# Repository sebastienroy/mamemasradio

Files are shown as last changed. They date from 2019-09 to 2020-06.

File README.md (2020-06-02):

# Mamema's radio
A web radio receiver with a classical hifi style ergonomy

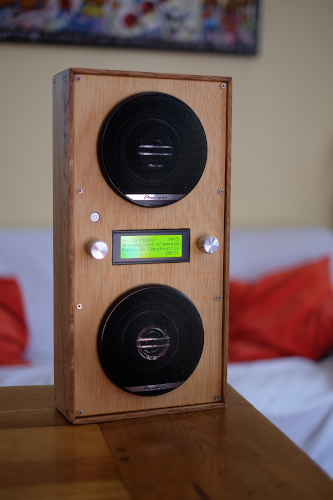
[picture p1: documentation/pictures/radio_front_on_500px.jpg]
Mamema's radio


## History

During the hollidays of my children, I've asked my mother, the grandmother of my children, to babysit them. During this period, my children were often listening to FIP radio (www.fip.fr) on the FM. My mother really liked listening to this radio. Unfortunately, when she was back to home, she couldn't listen to it any more because the FM station is not vailable where she lives (in the north of Alsace, France).
This gave me an idea of Christmas present : I decided to build a radio receiver. Instead of receiving the radio stream from FM, the receiver will get it from web. A quick tour on some web stores shown me that webradio receiver are available for purchasing, however the receiver I wanted for my mother had to meet the following two requirements :
* To be very easy to use, having an ergonomy very close to a traditional FM radio receiver
* Being highly customisable (and customized), in order to help her, each time she listens to the radio, to have a though for her children and grandchildren.

In Alsace, where she lives, the word for "Grandmother" is "Mamema". This is the word my children use for her, and so this is the name I used for this radio receiver.

## Features
* Plays audio stream through wifi network. No limit for the number of programmable radio stations
* Can also be used as a bluetooth speaker
* Uses classics physical commands : power button, rotary buttons
* Built around a raspberry pi zero low cost - low power consumption nano computer
* Excellent audio quality : uses a high quality sound card.
* Displays personnalisable messages and birthdays reminders : perfect as a present for your family members. No limitation for the length of the message, the text scrolls if wider than the screen
* Can be built as a standalone radio, integrating speakers and an amplifier, or as an audio source for a separated stereo amplifier

## General design
### Hardware
* Raspberry Pi Zero W
* Soundcard :  Hifiberry Miniamp (standalone radio), or Hifiberry DAC+ Zero (audio source for external hifi amplifier)
* Loud speakers (standalone radio)
* Man-Machine interface elements : LCD display, rotary encoder, power button
* Interface pcb and accessories pcb : a way to make electrical links from the Raspberry GPIO ports and the interface elements. To be manufactured by a dedicated factory (links provided)
* Casing.
### Software
* Radio stream player (Music Player Daemon)
* User interactions managed by python software components (specific developments)
* Based on Raspbian operating system

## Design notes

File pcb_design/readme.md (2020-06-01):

# Mamema's radio pcb design
This directory contains the design document describing the pcb design of the webradio.

The pcb consists in a main interface pcb and some accessories pcb

* Main pcb :

main pcb schema

* Accessories pcb :

accessories pcb schema

## Purpose of the pcb
The Mamema's radio hardware consists in the following components
* A Raspberry pi zero W nano computer
* A sound card (hifiberry miniamp, or DAC+ zero)
* A power button
* A 4x20 LCD display
* 1 or 2 rotary encoders

All these elements are driven from the Raspberry pi GPIO connector. However, because the soundcard is blugged as a hat onto the GPIO port, if the sound courd is plugged directly on the GPIO port, the port would not be available for other physical components.
The idea is then to insert a PCB between the raspberry pi and the sound card, so that the sound card can have access to needed pins, and the remaining free pins are available for the other physical components.

## Manufacturing
Main PCB and accessories PCB may be manufactured directly using these links :
* Main PCB :
https://aisler.net/p/ENDPOVDQ
* Accessories PCB :
https://aisler.net/p/QHNAFNPG

The accessories board has to be cut into 6 parts : 4 rotary encoder supports, and 2 power button supports. Thus, one accessories board can be used to make two separate Mamema's radios.

The design has been made using Fritzing 0.9.3b.
Unfortunately, Fritzing org currently asks people for paying to download the software, witch was not the case when Mamema's radio design was made.
If you don't want to pay, you can still compile the sources by yourself.

## Design documents

* webradio_pcb.fzz document describes the main pcb of the web radio. It is used to connect the raspberry pi zero w component to an LCD display, a power button, a rotary encoder used to change the radio station, and optionnaly to another rotary encoder that can be used to change the volume. This pcb also holds a logic level converter (in order to convert voltage from 3.3V from the raspberry to 5V for the LCD display) and a resistor needed for the power button LED.
* accessories_pcb.fzz document describes accessories pcb. The described pcb has to be cut into 6 parts as described above. These parts are used as support to connect the rotary encoder and the power button, but they are also used to attach these components on the case of the radio. The power button in particular cannot be attached on the case by itself.

The connection between the main pcb and the accessories pcb use F2510-4P connectors. The male F2510-4P headers are soldered on the main pcbs, male dupont headers are soldered on the accessories pcb.
Wires are used between them.
The female headers are used from the main pcb to the accessories pcb.

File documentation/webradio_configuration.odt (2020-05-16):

# Installation Raspbian

Gravage de la carte SD à partir de la distrib raspbian strech lite

# Personnalisation de l’OS

Se connecter avec un clavier et un écran, brancher l’alim

L’utilisateur par défaut est : pi

le mot de passe par défaut est : raspberry

Taper sudo raspi-config

- configurer le clavier : le mettre en Francais
- Configurer le wifi
- Configurer le hostname (webradio par exemple)
- Configurer un nouveau mot de passe
- Autoriser l’interface i2c
- Autoriser SSH
- Valider
- Rebooter et noter l’adresse IP. Le reste pourra se faire par SSH

# Activation et configuration du module logiciel I²C

Voire référence en fin de document

On ajoute les modules au démarrage :

sudo nano /etc/modules

Ajouter ces 2 lignes :

i2c-bcm2708

i2c-dev

On redémarre :

sudo reboot

On installe les outils nécessaires :

sudo apt-get install python-smbus i2c-tools

On va utiliser la commande i2cdetect, qui permet de voir la liste des périphériques I²C reliés au Pi. La commande est différente si vous utilisez un Raspberry Pi Rev 1 ou Rev 2 (l’adresse du bus I²C est différente), donc choisissez la bonne :

sudo i2cdetect -y 1

0 1 2 3 4 5 6 7 8 9 a b c d e f

00: -- -- -- -- -- -- -- -- -- -- -- -- --

10: -- -- -- -- -- -- -- -- -- -- -- -- -- -- -- --

20: -- -- -- -- -- -- -- 27 -- -- -- -- -- -- -- --

30: -- -- -- -- -- -- -- -- -- -- -- -- -- -- -- --

40: -- -- -- -- -- -- -- -- -- -- -- -- -- -- -- --

50: -- -- -- -- -- -- -- -- -- -- -- -- -- -- -- --

60: -- -- -- -- -- -- -- -- -- -- -- -- -- -- -- --

70: -- -- -- -- -- -- -- --

Ici, on peut voir qu’il y a un composant i2c, à l’adresse 0x27.

Il faudra reporter cette valeur dans le fichier webradio.cfg :

Dans ce dernier fichier, vous pouvez ajuster l’adresse de votre écran si ce n’est pas 27 :

[hardware]

# i2c address of the lcd device

lcd_address: 0x27

## Utilisateur par défaut

On laisse pi, ya pas de pb avec ça

# Partage du répertoire de configuration (optionnel)

Il est aussi possible d’utiliser sftp (ssh) à la place.

L’info est détaillée là :

https://raspberrypihq.com/how-to-share-a-folder-with-a-windows-computer-from-a-raspberry-pi/

Installer smb :

sudo apt-get update

sudo apt-get install samba samba-common-bin

Créer un répertoire de partage :

mkdir /home/pi/share

Editer le fichier de conf de Samba :

sudo nano /etc/samba/smb.conf

Assurez vous que les paramètres suivants sont positionnés :

workgroup = WORKGROUP

wins support = yes

Rajoutez la section suivante :

[RadioShare]

comment=Webradio Share

path=/home/pi/share

browseable=Yes

writeable=Yes

only guest=no

create mask=0777

directory mask=0777

public=no

Enregistrer et quitter.

Créer un utilisateur smb :

sudo smbpasswd -a pi

# Installation du logiciel radio

## Copie des fichiers

Copie des fichiers à partir du répertoire partagé RadioShare

Copier les fichiers dans /home/pi/webradio

## configuration pour démarrage auto de la radio

Vérifier que les paths figurant dans /home/pi/webradio/webradio.sh sont ceux attendus

Copier le fichier weradio.sh dans /etc/rc.local/

sudo cp /home/pi/webradio/webradio.sh /etc/rc.local

# Configuration de la carte son

Dans le fichier /boot/config.txt

Enlever la ligne

dtparam=audio=on

Rajouter la ligne

dtoverlay=hifiberry-dac

# Installer MPD

Sudo apt-get update

Sudo apt-get install mpd mpc

Puis rebooter : sudo reboot

# Configuration du volume

Créer un fichier /etc/asound.conf contenant :

pcm.hifiberry {

type softvol

slave.pcm "plughw:0"

control.name "Master"

control.card 0

}

pcm.!default {

type plug

slave.pcm "hifiberry"

}

Modifier le fichier /etc/mpd.conf : la section audio_output{…} doit contenir ceci :

audio_output {

enabled "yes"

type "alsa"

name "HiFiBerry Miniamp"

device "hifiberry"

auto_resample "no"

auto_channels "no"

auto_format "no"

dop "no"

mixer_control "Master" # optional

mixer_type "hardware" # optional

}

sudo reboot

# tester le son et le flux radio

mpc add http://str0.creacast.com/rec

mpc play 1

# Configurer le bluetooth

Le seul parametre à modifier au déploiement est nécessaire à la configuration du raspberry en tant que « a2dp receiver ». (advanced audio distribution profile)

Ouvrez le fichier de configuration de bluealsa :

sudo nano /lib/systemd/system/bluealsa.service

Cherchez la ligne qui commence par « ExecStart » et rajoutez l’option du profile a2dp comme ci-dessous :

ExecStart=/usr/bin/bluealsa -p a2dp-sink

# Configurer un agent bluetooth

https://gist.github.com/mill1000/74c7473ee3b4a5b13f6325e9994ff84c

# Webradio

Copier les sources python dans le répertoire webradio

Installer les dépendances python :

Rpi.GPIO :

sudo apt-get install python-rpi.gpio python3-rpi.gpio

RPLCD :

sudo apt install python3-smbus

sudo apt-get install python3-pip

sudo pip3 install RPLCD

# Startup at boot

Rajouter dans le fichier /etc/rc.local

python3 /home/pi/python/webradio/mamemasradio.py > /dev/null &

# Ecrire les logs systeme en RAM

Editer le fichier /etc/fstab

Rajouter les lignes suivantes :

tmpfs /tmp tmpfs defaults,noatime,nosuid,size=10m 0 0

tmpfs /var/tmp tmpfs defaults,noatime,nosuid,size=10m 0 0

tmpfs /var/log tmpfs defaults,noatime,nosuid,mode=0755,size=10m 0 0

tmpfs /var/log/mpd tmpfs defaults,noatime,nosuid,mode=0755,size=10m 0 0

# Modifier le mot de passe

Nouveau mot de passe :

Nicole-48

Taper la commande

passwd

Le mot de passe initial est

raspberry

# Références

http://hardware-libre.fr/2014/03/raspberry-pi-utiliser-un-lcd-4x20/

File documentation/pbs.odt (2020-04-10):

Hardware

Ref | Nom | Commentaire | Nb
1 | Raspberry pi zero w | | 1
2 | 40 pins header | | 1
3 | Carte micro SD | | 1
4 | Alimentation | | 1
5 | Carte son | Avec ou sans ampli intégré | 1
| Motherboard
6 | Pcb « motherboard »
7 | Header motherboard | | 1
8 | Logic level converter | Header inclus | 1
9 | Résistance 470 ohms | | 1
10 | Connecteur KC2510-4P male | | 4
11 | Connecteur KC2510-4P femelle | | 4
12 | Header KC2510 | | 16
13 | Vis M2.5 40mm | | 4
14 | Ecrou M2.5 | | 4
15 | Tube « spacer »
| Accessoires
16 | Pcb « accessoires » | | 1
17 | LCD 2004 | | 1
18 | Interface i2c pour lcd | | 1
19 | Encodeur rotatif | 1 ou 2 suivant carte son | 2
20 | Bouton « volume » | 1 ou 2 suivant carte son | 2
21 | Interrupteur « Power » | | 1
22 | Dupont 4P male header 90° | Retaillage de barettes de 40 pins | 3
23 | Dupont 4P female | | 4
24 | Dupont female connector | | 16
25 | Cable nappe AP x 20cm | | 4
| Haut parleurs
| Housing

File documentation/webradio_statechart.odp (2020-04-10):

## Webradio statechart

On

Off

power_bt

Sleep

volume_rot

Playing

station_rot

Choosing

Volume

timeout

power_bt

station_sw + power_bt

volume_rot

station_sw / timeout

Choose SSID

station_rot

station_sw

Choose pwd

validate

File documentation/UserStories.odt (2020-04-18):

UserStories

# Welcome message

## Goal

En tant qu’utilisateur de la radio,

Je veux dans l’affichage d’un message de bienvenue sur l’affichage de la radio,

Afin que je sache que c’est un appareil personnalisé

## Details

La zone du message de bienvenue est la partie gauche de la première ligne

16 caractères au maximum peuvent etre affichés

Le message doit pouvoir etre configuré : il ne doit pas etre ecrit en dur dans le code. Il doit etre accessible dans un fichier potentiellement partageable sur le réseau

LCD :

W | e | l | c | o | m | e | | m | e | s | s | a | g | e | | Wi | fi | le | vel
M | e | s | s | a | g | e | | p | e | r | s | o | n | n | a | l | i | s | é

Configuration :

On va dire que le fichier de configuration se trouve dans : ~/webradio/conf

# Wifi level

## Goal

En tant qu’utilisateur de la radio,

Je veux connaître la qualité de réception wifi,

Afin, en cas de pb de réception, de pouvoir savoir si cela est dû à un pb wifi

## Details

La qualité de reception est affiché sur 4 caractères : <symbole wifi><Valeur 0 à 5>’/5’

Le niveau du signal est à réactualiser régulièrement, mettons toutes les 5 secondes

Commandes système à parser :

sudo iwlist wlan0 scan

iwgetid

Le symbole wifi est un caractère spécial :

# Message Personnalisé

## Goal

En tant qu’utilisateur de la radio,

Je veux voir un message personnalisé différent à chaque fois que j’allume la radio,

Pour m’inciter d’autant plus à allumer la radio

## Details

Le message personnalisé est écrit dans les 20 caractères de la deuxieme ligne

Il est prix au hasard dans une liste décrite en configuration et changé à chaque allumage de la radio

# LCD On/Off

## Goal

En tant qu’utilisateur de la radio,

Je veux pouvoir l’allumer et l’éteindre d’un click de bouton

Afin que cela soit simple et rapide

## Details

Un interrupteur poussoir sert à allumer et à eteindre.

Lorsqu’on eteint, le retro-eclairage du lcd s’eteint et un message de veille est affiché

Lorsqu’on allume, le rétro-eclairage s’allume et tout ce qui doit s’afficher s’affiche.

Une led permet de visualiser l’état du bouton, s’il s’agit d’un bouton retro éclairé

# Radio On/Off

## Goal

En tant qu’utilisateur de la radio,

Je veux que la radio soit diffusée ou pas selon l’etat on/off de la radio

Pour que ce soit vraiment une radio

## Details

Dans un premier temps, on considère que des flux ont déjà été configurés, on se contentera de faire un ‘mpc play 1’ et un ‘mpc stop’

# Stream information

## Goal

En tant qu’auditeur de la radio,

Je veux que soit affichés le nom de la radio et le titre du morceau en cours, si disponible,

Afin de savoir sur quel flux radio je suis quelle musique que j’écoute

## Details

Le nom de la radio est affiché sur la 3e ligne

Le titre du morceau est affiché sur la 4e ligne

Si le nom de la radio n’est pas disponible, il doit y avoir un nom donné par la configuration à l’URL du flux

Si nom du morceau n’est pas disponible, il faut afficher une info dans ce sens, genre « Pas de titre disponible »

Il faut que le titre soit régulièrement mis à jour, car les morceaux changent

Il faut un mécanisme de défilement du nom et du titre, s’ils dépassent les 20 caractères afin de pouvoir lire en entier les valeurs.

W | e | l | c | o | m | e | | m | e | s | s | a | g | e | | Wi | fi | le | vel
M | e | s | s | a | g | e | | p | e | r | s | o | n | n | a | l | i | s | é
N | o | m | | r | a | d | i | o
T | i | t | r | e | | m | o | r | c | e | a | u

# Text scroll

## Goal

En tant qu’utilisateur de la radio

Je veux que le texte scrolle lorsqu’il est plus long que la taille de la ligne

Afin de pouvoir lire l’intégralité du texte

## Details

La vitesse doit pouvoir etre configurée

Il doit y avoir une pause en début et fin de scroll. Ces pauses sont également configurables

# Stream Choice

## Goal

En tant qu’utilisateur de la radio

Je veux pouvoir changer la station en tournant un bouton

Afin de zapper d’un flux à un autre

## Details

Lorsqu’on tourne l’encodeur rotatif, on affiché, dans les lignes 2 à 4 :

- Changer pour :
- <numero station> : <nom station>
- appuyer pour valider

Lorsqu’on laisse plus d’un certain delai (configurable), on retourne dans le mode « playing »

Il faut appuyer sur l’encodeur pour valider

Le numero de la station est son rang dans le fichier de configuration

Le nom de la station est le nom de l’entrée dans le fichier de conf

La station en cours de lecture est mémorisée :

- pour le on/off logique : on joue la derniere en cours
- pour la sélection : on propose celle avant ou après, selon le sens de rotation

Attention à bien initialiser la liste des stations dans mpd avec la liste lue en conf

« mpc clear »

« mpc add <url> »

Au hard reboot, on lit la station n°1

# Messages personnalisés datés

## Goal

En tant qu’utilisateur de la radio,

Je veux que la radio affiche des messages dépendant de la date du jour,

Afin d’avoir un rappel des anniversaires et autre dates remarquables

## Description

Il y a une section dans le fichier de conf qui doit etre consacrée à cela, de facon qu’on ai directement clé = date ; valeur = message

# Affichage adresse IP

## Goal

En tant que configurateur de la radio,

Je veux pouvoir connaître l’adresse IP de la radio

afin de pouvoir facilement la maintenance de la radio

## Description

On peut par exemple afficher l’adresse IP lorsque la radio est en veille et qu’on appuie sur le bouton de sélection des stations.

Pour récuper l’adresse IP, le plus simple est d’executer la commande ‘hostname -I’

# Modification de la configuration

## Goal

En tant qu’administrateur de la radio,

je veux pouvoir accéder au fichier de configuration,

Afin de pouvoir en modifier les valeurs, et notamment les flux radio enregistrés

## Description

Le plus simple est de partager le fichier de conf via samba.

# Configuration du wifi via l’interface lcd

## Goal

En tant qu’administrateur de l’interface,

je veux pouvoir configurer le reseau wifi en utilisant uniquement l’interface lcd

Afin de pouvoir faire la config sans devoir brancher un clavier et un écran

## Description

Lorsque la radio est eteinte (mais pas le raspberry : mode off), un appui sur le rotary encodeur puis sur le bouton power (sans relacher le rotary encoder) fait entrer dans le mode configuration du wifi.

Ce mode permet de choisir successivement un réseau puis un mot de passe

Après avoir effectué les appuis simultanés, l’administrateur se trouve sur un écran qui comporte les lignes suivantes :

C | h | o | i | x | | d | u | | r | e | s | e | a | u
T | o | u | r | n | e | r | | p | o | u | r | | c | h | a | n | g | e | r
A | p | p | u | y | e | r | | p | o | u | r | | v | a | l | i | d | e | r
< | S | S | I | D | >

Où <SSID> correspond au premier nom de reseau wifi trouvé

En tournant l’encodeur, l’utilisateur peut faire défiler les noms de reseau wifi détectés.

Lorsque l’utilisateur appuie sur l’encodeur, le SSID affiché est validé et l’on passe au choix du mot de passe :

E | n | t | r | e | z | | l | e | | p | w | d | | r | e | s | e | a | u
↵ | | p | o | u | r | | v | a | l | i | d | e | r
A | B | C | D | E | F | G | H | I | J | K | L | M | N | O | P | Q | R | S | T
< | p | w | d | >

La troisieme ligne contient les 20 premiers caracteres affichables par le lcd.

La quatrieme ligne contient le mot de passe en cours d’edition.

Initialement, le premier caractère de la ligne 3 est en surbrillance (caractère ‘A’). Lorsque l’utilisateur tourne l’encodeur le curseur est déplacé sur la droite, ou sur la gauche. Lorsque le curseur atteint le bord droit ou le bord gauche de l’écran, ce sont les caractères qui sont déplacé dans le sens inverse.

L’avant dernier caractère permet d’effacer, le dernier caractère permet de valider.

Lorsque l’encodeur est pressé, le caractère en surbrillance est rajouté au mot de passe, ou selon le caractère selectionné, le dernier caractère est effacé ou le mot de passe est confirmé.

Une fois le mot de passe confirmé, la radio reboote.

Durant la sélection du reseau wifi ou du mot de passe, l’appui sur le bouton power permet d’annuler lasélection et rallume la radio (qui ne joue rien s’il n’y a pas de connection wifi)

# Ligne de commande

# Goal

En tant que configurateur de la radio,

je veux pouvoir définir des paramètres dans la ligne de commande,

Afin de pouvoir mes paramètres de lancement sans devoir changer le code python

## Description

Utilisation de argparse afin de gérer les arguments.

Si pas de précision, le fichier de conf est conf.txt dans le répertoire courant. Sinon, c’est l’argument (-c, --config) qui donne le path du fichier de configuration.

Il faut aussi définir où sont envoyés les sorties : écran ou fichier de log. Utilisation d’un logger ?

Il y a bien sur (-h, --help) qui donne l’usage de la ligne de commande.

# Tests unitaires

## Goal

En tant qu’IVQ,

Je veux que les tests du code python soit effectués dans des fichiers séparés,

afin que ces tests soient faits dans les regles de l’art

## Description

Pas poluer les imports avec du code destiné aux tests

pouvoir modifier les tests sans risque de régression du code

automatisation

Utilisation du framework unittest

# PCB

## Goal

En tant qu’intégrateur,

Je veux des pcb pour connecter tous mes composants

afin de ne pas me noyer avec plein de fils à souder dans tous les sens sur des plaques à trous

## Description

Utilisation de Fritzing pour dessiner les schémas de la main board et aussi des mini plaques sur lesquelles sont fixés l’encodeur rotatif et le bouton power.

Tant qu’à faire, on peut anticiper la présence d’un encodeur pour le volume.

# Bouton volume

## Goal

En tant qu’utilisateur d’une radio à ampli intégrée,

Je veux avoir un bouton volume

Afin de pouvoir régler le volume sonore de la radio

## Description

Ce bouton ne sera présent que sur les variantes avec ampli intégré (hifiberry miniamp).

Mais le connecteur est sur tous pcb, ca ne mange pas de pain, et le soft peut également est prévu de façon générique.

Le bouton est à action immédiate, pas besoin de valider.

L’incrément est reglagle par configuration (par pas de 1 %, 5 %, 10 %, etc)

L’utilisation de l’encodeur de volume utilise les deux lignes du bas :

Ligne 3 vide

Ligne 4 : Volume <vol>

Ou <vol> vaut entre 0 et 100

L’affichage se remet en « playing state » au bout d’un temps configurable.

# Affichage de l’heure

## Goal

En tant qu’utilisateur de la radio, je veux que la radio affiche l’heure.

## Description

Lorsqu’elle est eteinte, il y a de la place dans la première ligne du LCD.

Lorsqu’elle est allumée, on peut voir à l’afficher dans la dernière ligne, qui ne sert pas souvent. En effet, cette ligne est sencée afficher le nom du morceau, mais il est rarement renseigné dans les flux.

D’un autre côté, c’est dommage de se passer de cette fonction.

On peut donc couper la poire en prévoiyant une variable qui laisse le choix :

- Soit on affiche toujours l’heure
- Soit on affiche toujours le titre du morceau (même quand il n’est pas disponible)
- Soit on affiche l’heure lorsque le titre n’est pas disponible.

Ce choix est bien sûr à faire par configuration

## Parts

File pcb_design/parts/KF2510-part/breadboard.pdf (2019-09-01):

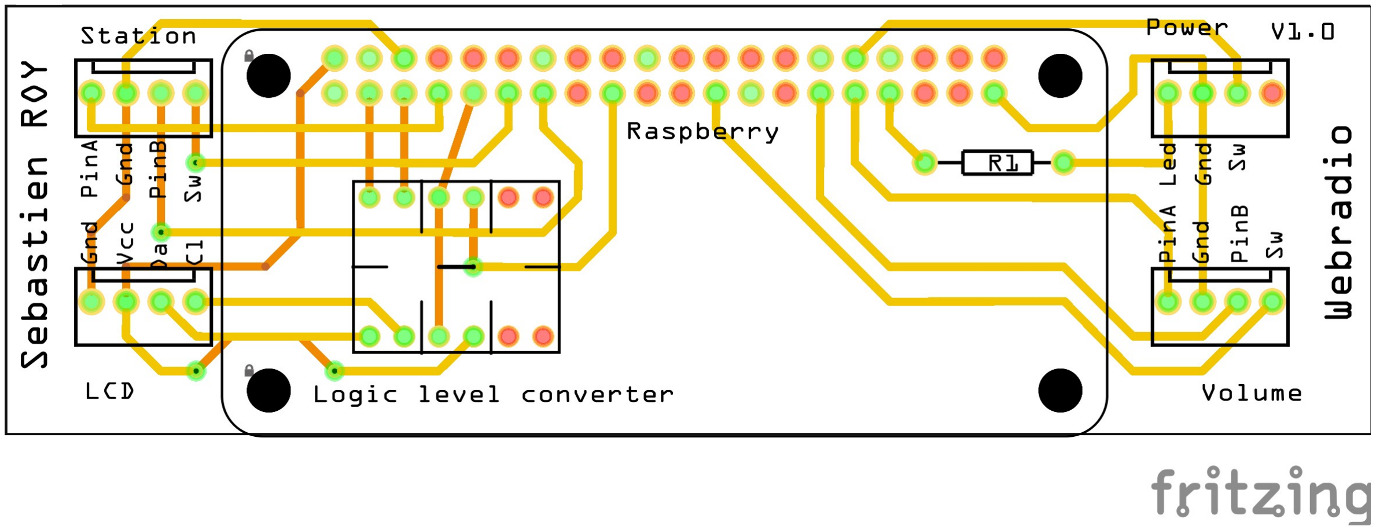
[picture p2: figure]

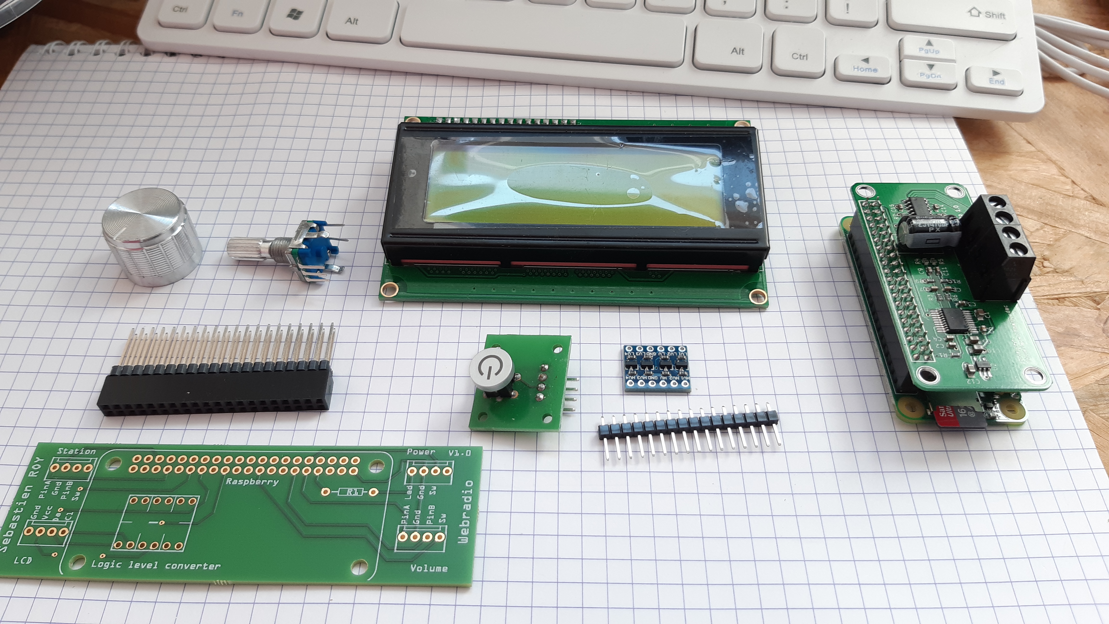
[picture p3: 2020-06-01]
documentation/pictures/fullres/components2.jpg

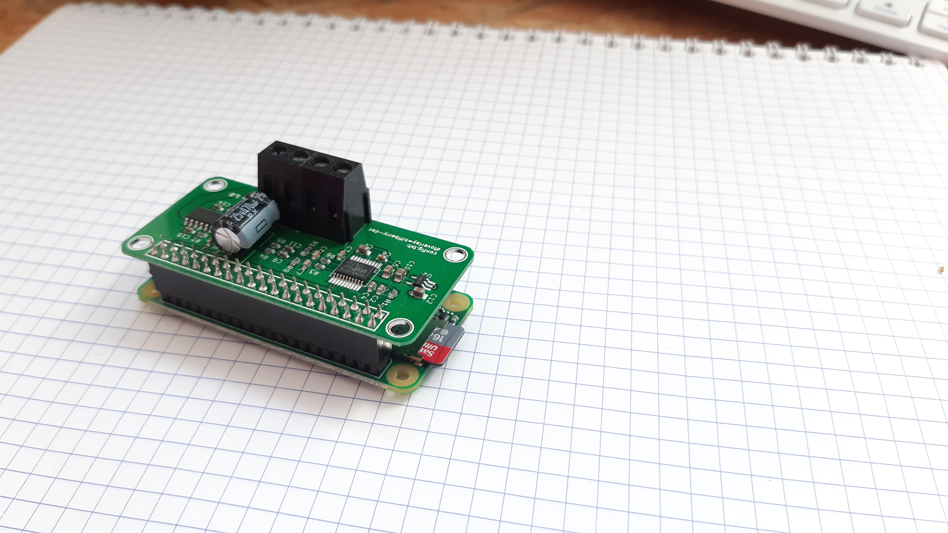
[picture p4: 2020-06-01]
documentation/pictures/fullres/components4.jpg

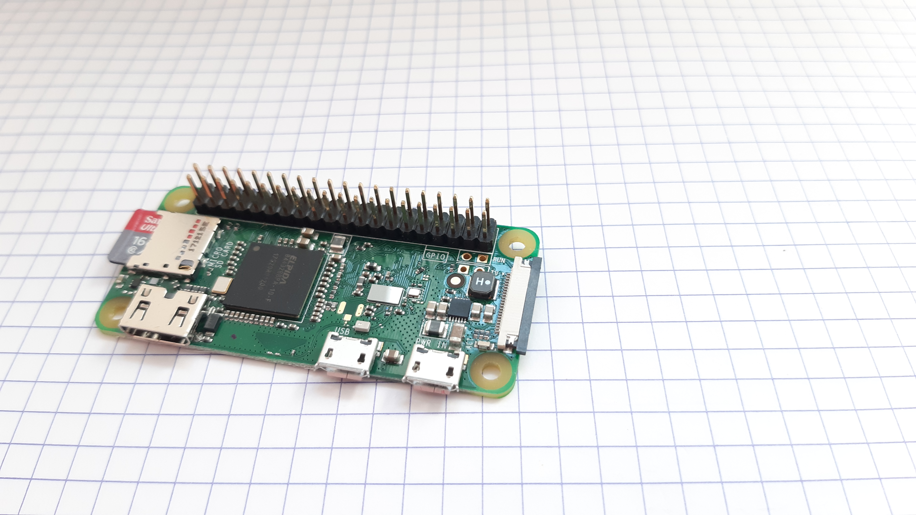
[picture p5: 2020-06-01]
documentation/pictures/fullres/components5.jpg

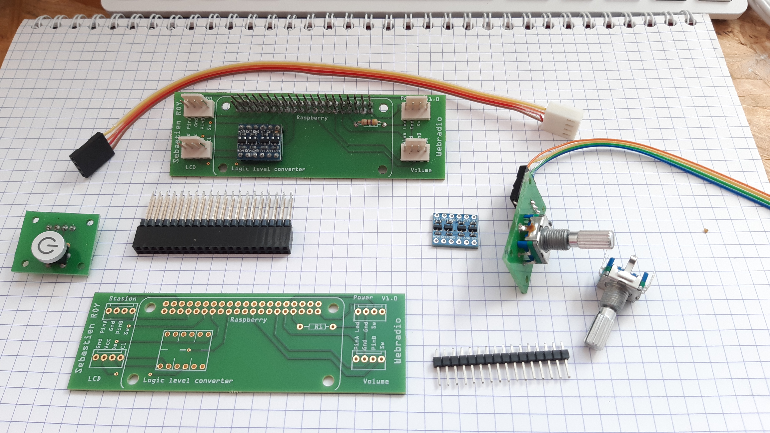
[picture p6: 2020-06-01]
documentation/pictures/fullres/components1.jpg

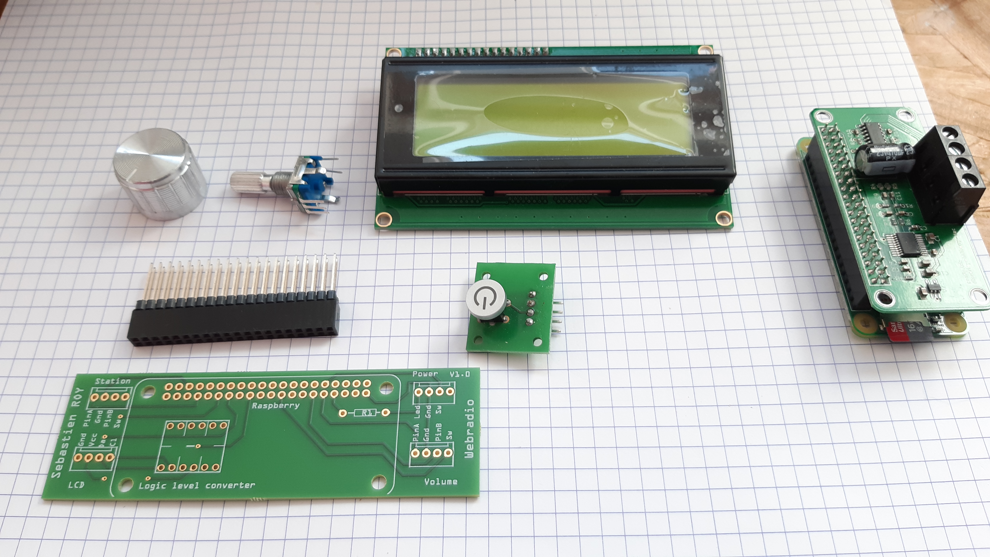
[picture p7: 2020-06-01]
documentation/pictures/fullres/components3.jpg

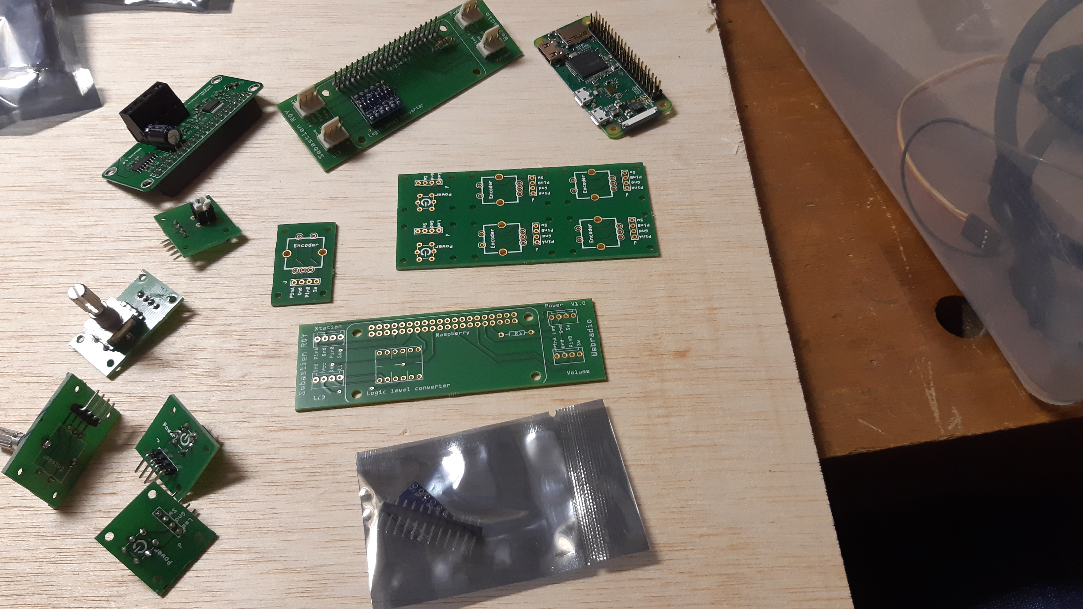
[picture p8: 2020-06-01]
documentation/pictures/fullres/components6.jpg

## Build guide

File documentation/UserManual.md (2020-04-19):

# Mamema's radio user manual
## Introduction
You are the owner of a Mamema's webradio. Congratulation !
Here is the user's manual, that will help you to set it up and to use it.
Enjoy!
## Setup of the radio
Mamema's radio is a web radio receiver. That means that the radio need to be connected to the internet in order to get the radio stream.
That's why the first step to do with your radio is to configure the wifi connection. 
This can be performed through the followin steps :
1. Note the ESSID (the name) and the password of the wifi network of the wifi router you want to connect to. This wifi router must be connected to the web.
2. Plug the power supply of the radio, and wait for the radio to go in sleeping mode (the LCD screen backlight is switched off).
3. **Press simultaneously on the radio station button, and on the power button**
4. The LCD screen backlight is then switched on, and you are now in the network choice mode. The last line of the screen displays a name of an available wifi network
5. Turning the radio station button changes the displayed network. Turn it until is displayed the network noted in step 1. then press the radio station button in order to validate your choice.
6. You need now to enter the password of the network. You need to select each character of the password, one after the other. To select a character, turn the radio station button to move the highlighted letter. Once arrived to the chosen character, press the button in order to select it. The selected characters are displayed in the bottom line. If you make a mistake, you can erase the last character using the character next to the last one of the selection line.
7. Once you have composed your password, please validate it using the last character of the selection line.

## Listen to the radio
Once the wifi connection is set up, you can switch the radio on using the power button.
When the radio is switched on, the selected radio station is played. 
To change de radio station, turn the radio station button, and press on it to select the chosen radio station.
The name of the played radio is displayed in the third line of the LCD screen. If the radio stream broadcasts the name of the currently played track, it is displayed in the fourth line of the screen. The current time is otherwise displayed.
In order to change the volume, use the volume button.
To configure the list of available radio stations, please read the administration manual.
## Text displayed
When the radio is on, a text is displayed on the second line. This text may depend on the current date, or be chosen randomly. See the administration manual for details.
## Trouble shooting
Q: The radio is switched on, but no sound is played
A: This may be due to one of the following causes :
1. The volume is set to 0. Turn clockwise the volume button
2. The wifi network is misconfigured. Check the setup part of this manual.
3. The wifi network is unreachable. Check the network quality level. If the value is 0/5, that means that the network is unreachable.
4. The wifi network is up, but the wifi router is not connected to the internet. 
5. The web broadcast url has changed or encounters some technical issue. Check it using another listening means, such as a personal computer.
## Reference
[Mamema's radio development site](https://github.com/sebastienroy/mamemasradio)

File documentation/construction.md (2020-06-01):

Radio front on

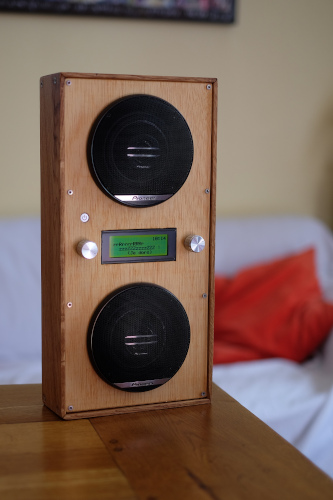
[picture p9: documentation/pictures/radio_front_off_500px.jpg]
Radio front off


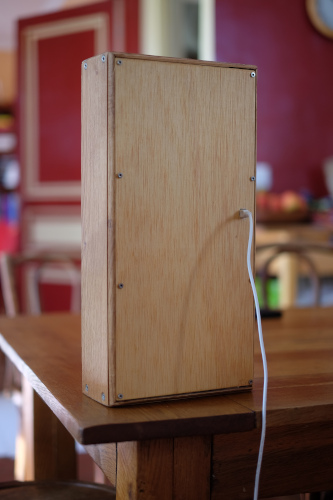
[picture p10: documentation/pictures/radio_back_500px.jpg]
Radio back


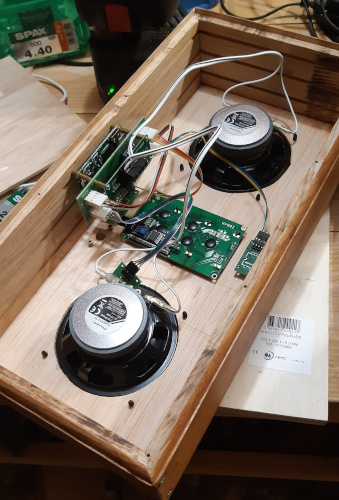
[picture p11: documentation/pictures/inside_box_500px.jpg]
Inside the box


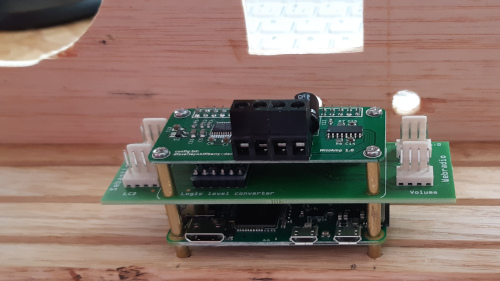
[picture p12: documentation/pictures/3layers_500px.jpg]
3 layers


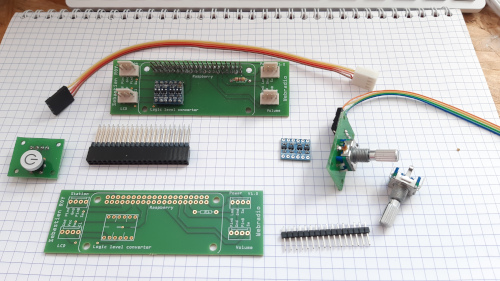
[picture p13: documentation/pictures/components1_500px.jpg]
Components


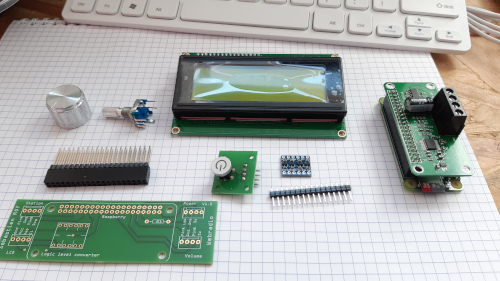
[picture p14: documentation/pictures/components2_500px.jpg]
Components


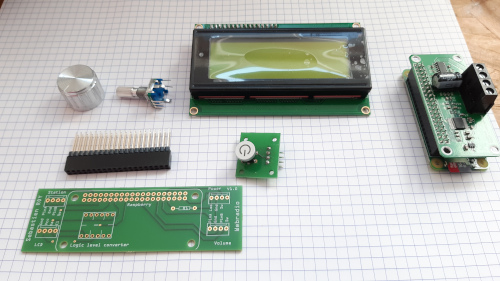
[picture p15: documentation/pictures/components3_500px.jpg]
Components


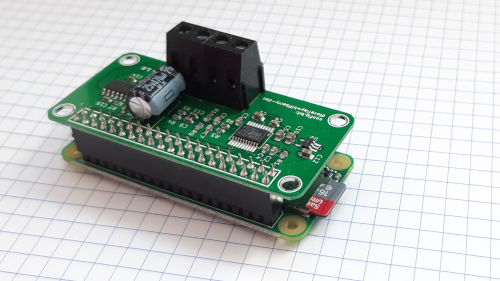
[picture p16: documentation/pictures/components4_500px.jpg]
Components


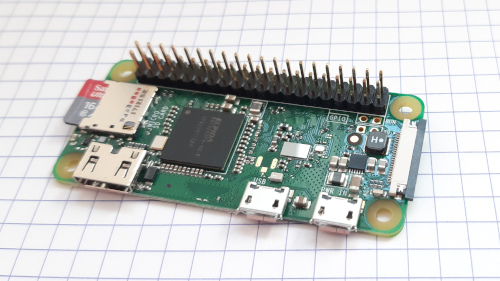
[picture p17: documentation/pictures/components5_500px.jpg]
Components


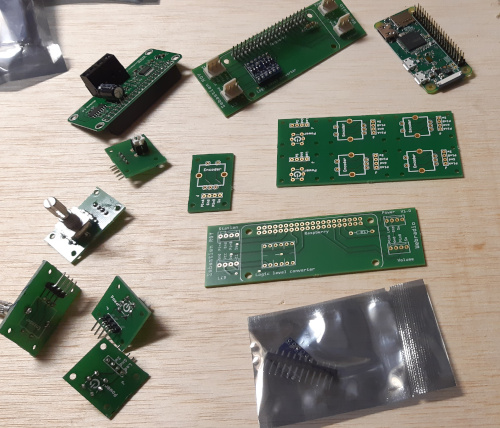
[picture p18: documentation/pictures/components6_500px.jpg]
Components


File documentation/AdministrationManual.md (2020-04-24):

# Mamema's radio administration manual
## Introduction

Mamema's radio is basicaly composed of a raspberry pi computer, a soundcard, some interface components (lcd screen, rotary button, power button), and all the software that make all this working together.
The software is parameterized through a configuration file. The aim of this administration guide is to explain how to access to this configuration file, and wich part can be modified safely.
The audience of this manual is people that are confident with computer configuration.
This manual and other documentation can be found on the Mamema's repository :
http://github.com/sebastienroy/mamemasradio

This manual describes the following administration actions of the Mamema's webradio. 
1. Wifi setup (alternative method)
2. Access to the configuration file
3. Modifications of the configuration file

## 1. Wifi setup (alternative method)
In order to access to the radio streams, but als in order to conduct the administration actions, Mamema's radio needs first to be connected to your wifi network.
The configuration of the wifi network is already described in the user manual. However, for any reason, you may want to configure the network in another maner.
Unlike otherwise configured (we recommand to configure another password and to write it somewhere), the login/password of the user is pi/raspberry.
You can configure the wifi ssid and password of the wifi network by :
1. dismount the rear pannel of the radio
2. connect a keyboard on the usb port of the raspberry pi board
3. connect a screen on the hdmi port of the raspberry pi
4. modify the `wpa_supplicant.conf` file :
 
`sudo nano /etc/wpa_supplicant/wpa_supplicant.conf`

Go to the bottom of the file and add the following:
```
network={
    ssid="yourSSID"
    psk="yourPassword"
}
```
With `yourSSID` and `yourPassword` adapted to your local wifi network
Then reboot :
`sudo reboot`
Your radio should have now access to the wifi network.
You can now disconnect your screen, your keyboard and close the back of the radio case. The rest of the administration actions will be done remotely.

## 2. Access to the configuration file
All the configuration of the radio (list of radios, displayed messages, ...) is defined in a configuration file : 
`/home/pi/webradio.cfg`
You can access to this file through 2 different methods (both actually use the same network protocol)
### 1. Using an ftp client
From another computer, use a ftp client, such as FileZilla to open an ftp session. 
Use the following parameters :
* Protocol : SFTP (SSH File Transfer Protocol)
* Host : mamemasradio, or another name, depending on your local configuration (you can also use the ip address of the radio. When the radio is off, press on the radio station button, the ip address will be displayed)
*  Port : leave empty, 
* User : `pi`
* Password : `raspberry` is the default password, but you may have configured another one.

Once connected, you have access to the configuration file :
`/home/pi/webradio.cfg`
### 2. Using ssh
You can open directly an ssh session from another computer to the radio :
`ssh pi@mamemasradio`
you can modify the configuration file using the following command :
`nano /home/pi/webradio.cfg`
## 3. Modification of the configuration file
In the configuration file, some sections are intended to be modify, and some other not.
The sections that can be modified easily, without any particular risk are  the following :
* Random_messages
* Dated_messages
* Playlist
### Random_messages
In the random message section (that begins with `[random_messages]`), all the entries are messages that will be displayed randomly on the second line of the radio lcd display.
These messages are displayed randomly when there is no message related to the current date in the section `[dated_messages]`
Each entry begins with a labed, followed by a column. This label is not used for the display.
The message can be longuer than the size of the display (20 characters). In this case the message is scrolled automatically.
Exemple :
`1: Hello world!`
### Dated messages
In the section `[dated_messages]`, the configured messages depending on the date (in french format) corresponding to their label.
Example :
`25/12: Merry Christmas!`
This message will only be displayed the 25th of december.
### Playlist
The entries of the `[playlist]`section are the list of the titles and the url of the radio stations. They will appear in the same order as they appear in the configuration file.
There is not limit on the number of configured stations

There is a few additional thing you can freely configure. Be careful to not put the mess in the configuration.
1. Welcome message may be modified in the `[general]` section. Take care to not exceed 16 characters.
2. The clock format may be modified in order for instance to display the date/time in a more complete maner. The format is defined in the configuration file using the [clock]/format entry. The format definition may be found [in the description of the Python strftime function](https://strftime.org/). Be carefull to not exceed 20 characters.

## Reference
[Mamema's radio development site](https://github.com/sebastienroy/mamemasradio)

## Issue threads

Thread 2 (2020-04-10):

Disable miniamp power stage

sebastienroy, 2020-04-10:
When the webradio is built with the wifiberry miniamp sound card, there is a small noise that can be heard when the radio is switched off.

This is presumably due to the power stage of the sound card which is not totaly silent when no sound is played.
It could be interesting to test the swiching off of the power stage when the radio is off.
According to the Hifiberry documentation : https://www.hifiberry.com/docs/hardware/gpio-usage-of-hifiberry-boards/
> GPIO16 can be used to mute the power stage. GPIO26 shuts down the power stage.

This issue is here to check that

sebastienroy, 2020-04-10:
The power stage is muted or down when the output value is GPIO.LOW.

Closed 2020-04-10.

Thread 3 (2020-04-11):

Add bluetooth feature

sebastienroy, 2020-04-11:
It would be nice if the radio could behave as a bluetooth device when the it is switched off.
So that, it could be used to listen to podcasts for instance.

Interesting resources on bluetooth can be found there : https://www.sigmdel.ca/michel/ha/rpi/bluetooth_02_fr.html
And following :
https://www.sigmdel.ca/michel/ha/rpi/bluetooth_02_fr.html
https://gist.github.com/mill1000/74c7473ee3b4a5b13f6325e9994ff84c

sebastienroy, 2020-04-12:
First, following
https://www.sigmdel.ca/michel/ha/rpi/bluetooth_02_fr.html
and
https://scribles.net/updating-bluez-on-raspberry-pi-5-43-to-5-48/
I've updated the bluez library to 5.54
Can't remember th initial version. Maybe 5.50

sebastienroy, 2020-04-13:
This article is more recent:
https://scribles.net/streaming-bluetooth-audio-from-phone-to-raspberry-pi-using-alsa/

sebastienroy, 2020-04-13:
In order to send commands to the bluetoothctl service:
> echo -e "discoverbale on" | bluetoothctl

sebastienroy, 2020-04-20:
Interesting documentation:
https://www.linux-magazine.com/Issues/2017/197/Command-Line-bluetoothctl

sebastienroy, 2020-05-13:
This is the page of a bluetooth daemon :
https://github.com/lukasjapan/bt-speaker

sebastienroy, 2020-05-16:
Automatically accept bluetooth pairing :

https://raspberrypi.stackexchange.com/questions/50496/automatically-accept-bluetooth-pairings

Closed 2020-05-16.

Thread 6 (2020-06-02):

Configuration through web interface

sebastienroy, 2020-06-02:
It would be nice if the configuration could be done using web interface

sebastienroy, 2024-03-07:
Flask is a good candidate framework
The validation of forms can be made by Flask-WTF
https://github.com/sebastienroy/mamemasradio/issues/6

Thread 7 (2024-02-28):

Setup a wifi hotspot if no valid SSID

sebastienroy, 2024-02-28:
It could be nice to setup a wifi hotspot to allow access to the radspeberry pi and then configure the ssid
See https://www.raspberryconnect.com/projects/65-raspberrypi-hotspot-accesspoints/157-raspberry-pi-auto-wifi-hotspot-switch-internet

sebastienroy, 2024-02-28:
A webserver is needed to a user to connect to a configuration page.
The following webservers are availaible:
nginx
apache
lighttpd - https://www.lighttpd.net/

css form:
https://www.w3schools.com/css/css_form.asp

sebastienroy, 2024-02-28:
How to change the wifi credentials:

Installer Flask sur votre Raspberry Pi :
Assurez-vous que Python est installé, puis installez Flask en utilisant la commande suivante :

``` bash
pip install Flask
```
Créer le fichier Python pour le serveur web :
Créez un fichier app.py avec le contenu suivant :

``` python
from flask import Flask, render_template, request
import subprocess

app = Flask(__name__)

@app.route('/')
def index():
    return render_template('index.html')

@app.route('/update_wifi', methods=['POST'])
def update_wifi():
    ssid = request.form['ssid']
    password = request.form['password']

    # Utilisez subprocess pour modifier les identifiants WiFi
    # (Remplacez la commande en fonction de votre système d'exploitation)
    subprocess.run(['sudo', 'wpa_passphrase', ssid, password, '>>', '/etc/wpa_supplicant/wpa_supplicant.conf'])

    return "Identifiants WiFi mis à jour avec succès !"

if __name__ == '__main__':
    app.run(debug=True, host='0.0.0.0')
```
Créer le dossier templates et y ajouter le fichier HTML :
Créez un dossier templates dans le même répertoire que app.py, puis ajoutez un fichier HTML index.html avec le formulaire :

``` html
<!DOCTYPE html>
<html lang="fr">
<head>
    <meta charset="UTF-8">
    <meta name="viewport" content="width=device-width, initial-scale=1.0">
    <title>Modifier les identifiants WiFi</title>
</head>
<body>
    <h1>Modifier les identifiants WiFi</h1>
    <form action="/update_wifi" method="post">
        <label for="ssid">SSID:</label>
        <input type="text" id="ssid" name="ssid" required><br>
        <label for="password">Mot de passe:</label>
        <input type="password" id="password" name="password" required><br>
        <input type="submit" value="Enregistrer">
    </form>
</body>
</html>
```
Exécutez l'application Flask :
Ouvrez un terminal et exécutez le fichier app.py avec la commande :

``` bash
python app.py
```
Vous devriez voir un message indiquant que le serveur Flask est en cours d'exécution. Accédez au navigateur sur votre Raspberry Pi et allez à l'adresse http://localhost:5000 pour utiliser le formulaire.

Notez que cette approche est basique et ne gère pas la sécurité de manière exhaustive. Assurez-vous de prendre des mesures appropriées, comme utiliser HTTPS, pour protéger les informations sensibles, surtout si ce site est accessible depuis l'extérieur de votre réseau local.

sebastienroy, 2024-02-28:
Voici quelques étapes que vous pouvez suivre pour améliorer la conception de votre site web et le rendre adaptatif aux différents dispositifs.

Ajouter une feuille de style CSS :
Créez un fichier CSS dans le même dossier que votre fichier app.py. Nommez-le par exemple style.css.

Configurer le viewport :
Dans votre fichier HTML (index.html), assurez-vous d'avoir la balise <meta> pour définir le viewport. Cela permet aux navigateurs de rendre correctement la page sur les différents appareils.

``` html
<meta name="viewport" content="width=device-width, initial-scale=1.0">
```
Modifier le fichier style.css :
Ajoutez les règles CSS suivantes dans votre fichier style.css :

``` css

body {
    font-family: Arial, sans-serif;
    margin: 0;
    padding: 0;
    background-color: #f4f4f4;
}

h1 {
    text-align: center;
    color: #333;
}

form {
    max-width: 400px;
    margin: 0 auto;
    padding: 20px;
    background-color: #fff;
    box-shadow: 0 0 10px rgba(0, 0, 0, 0.1);
}

label {
    display: block;
    margin-bottom: 10px;
    color: #555;
}

input {
    width: 100%;
    padding: 10px;
    margin-bottom: 15px;
    box-sizing: border-box;
}

input[type="submit"] {
    background-color: #4caf50;
    color: white;
    cursor: pointer;
}

input[type="submit"]:hover {
    background-color: #45a049;
}
```
Ces règles CSS fournissent une base pour un design simple et propre. La propriété max-width: 400px; sur le formulaire limite sa largeur à 400 pixels, ce qui le rend adaptatif.

Inclure le fichier CSS dans le fichier HTML :
Ajoutez la balise <link> dans la section <head> de votre fichier HTML pour lier le fichier CSS :

``` html
<link rel="stylesheet" href="/static/style.css">
```
Assurez-vous que Flask sert les fichiers statiques correctement. Pour ce faire, ajoutez cette ligne dans votre fichier app.py :

```python
app = Flask(__name__, static_url_path='/static')
```
Et placez votre fichier style.css dans un dossier appelé static dans le même répertoire que votre fichier app.py.

Avec ces modifications, votre site web devrait avoir un design plus agréable et être adaptatif à différentes tailles d'écran. N'hésitez pas à ajuster les règles CSS en fonction de vos préférences de conception spécifiques.

sebastienroy, 2024-03-05:
See details for the configuration of wpa_supplicant.conf

https://raspberrypi.stackexchange.com/questions/11631/how-to-setup-multiple-wifi-networks

sebastienroy, 2024-03-05:
Allowed chars in SSID:
https://community.cisco.com/t5/wireless-mobility-knowledge-base/characteristics-of-ssids/ta-p/3131765

password:
https://community.tp-link.com/us/home/kb/detail/412692

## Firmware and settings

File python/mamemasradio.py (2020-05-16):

#!/usr/bin/env python3
# -*- coding: utf-8 -*-
"""
Created on Sun Sep 16 18:32:07 2018

@author: Sebastien Roy
"""

from queue import Queue
from threading import Thread, Event
import time
import subprocess
import argparse
import traceback
import logging

import RPi.GPIO as GPIO
from RPLCD.i2c import CharLCD

from resources import Resources
from wifiscanner import WifiScanner
from radioevents import WifiEvent, StationButtonEvent, VolumeButtonEvent, PowerButtonEvent
from radiocontext import RadioContext
from onstate import OnState
from offstate import OffState
from bluetoothstate import BluetoothState
from powerbutton import PowerButton
from encoder import RotaryEncoder

class WifiThread(Thread):
    """ A thread used to regulary check the wifi signal level
    """
    def __init__(self, callback):
        Thread.__init__(self)
        self._callback = callback
        self._stop = False
        self._pause = Event()

    def stop(self):
        """ Stops the thread
        """
        self._stop = True

    def pause(self):
        """ Pauses the thread
        """
        self._pause.clear()

    def resume(self):
        """ Resules the thread
        """
        self._pause.set()

    def run(self):
        scanner = WifiScanner()
        while not self._stop:
            self._pause.wait()
            scanner.scan_wifi()

            quality = 0 if scanner.current_cell is None else scanner.current_cell.quality
            event = WifiEvent(quality)
            self._callback(event)
            time.sleep(5)


class MamemasRadio:
    """ Main class for the mamema's radio software.

        It initializes all the needed resources
        and then launches the radio state in sleeping mode.
    """

    def _power_callback(self, originator, event_type):
        event = PowerButtonEvent(event_type)
        self._event_queue.put(event)

    def _wifi_callback(self, event):
        self._event_queue.put(event)

    def _station_callback(self, originator, event_type):
        event = StationButtonEvent(event_type)
        self._event_queue.put(event)

    def _volume_callback(self, originator, event_type):
        event = VolumeButtonEvent(event_type)
        self._event_queue.put(event)

    def __init__(self, conf_path):
        self.logger = logging.getLogger(type(self).__name__)

        # Context initialisation

        self._rsc = Resources(conf_path)
        self._event_queue = Queue()
        self._init_playlist()
        self._init_soundcard()
        lcd = self._init_lcd()
        power_button = PowerButton(self._rsc.power_switch, self._rsc.power_led, None)
        power_button.callback = self._power_callback
        station_gpios = self._rsc.station_button
        self._station_button = RotaryEncoder(station_gpios[0],
                                             station_gpios[1],
                                             station_gpios[2],
                                             callback=self._station_callback)
        volume_gpios = self._rsc.volume_button
        self._volume_button = RotaryEncoder(volume_gpios[0],
                                            volume_gpios[1],
                                            volume_gpios[2],
                                            callback=self._volume_callback)

        self._wifi_thread = WifiThread(self._wifi_callback)
        self._ctxt = RadioContext(self._rsc, lcd, power_button,
                                  self._station_button,
                                  self._volume_button,
                                  self._wifi_thread,
                                  self._event_queue)

        self._on_state = OnState(self._ctxt, self)
        self._off_state = OffState(self._ctxt, self)
        self._bt_state = BluetoothState(self._ctxt, self)
        self._state = None
        # set callbacks

    def switch_radio(self, value):
        """ This method is called when the power button is pressed.
            The result is switching on or off the radio
        """
        if self._state is self._on_state and value:
            self.logger.error("Switch on when switched on should not happen")
        elif self._state is self._off_state and not value:
            self.logger.error("Switch off when switched off should not happen")
        else:
            self._state.leave_state()
            self._state = self._on_state if value else self._off_state
            self._state.enter_state()
            
    def switch_to_bluetooth(self):
        """ This method is called when radio station button is pressed an
                released when it is in sleeping mode
        """
        if self._state is self._bt_state:
            self.logger.error("Switch to bluetooth when already in bluetooth mode")
        else:
            self._state.leave_state()
            self._state = self._bt_state
            self._state.enter_state()

    def _init_playlist(self):
        subprocess.call(["mpc", "clear"])
        playlist = self._rsc.playlist
        for entry, url in playlist:
            subprocess.call(["mpc", "add", url])

    def _init_lcd(self):
        lcd = CharLCD(i2c_expander='PCF8574', address=self._rsc.lcd_address,
                      port=1,
                      cols=20, rows=4, dotsize=8,
                      charmap='A00',
                      auto_linebreaks=True,
                      backlight_enabled=False)
        #self._lcd.backlight_enabled = False
        lcd.cursor_mode = "hide"
        wifi_char = (
            0b00000,
            0b11111,
            0b00000,
            0b01110,
            0b00000,
            0b00100,
            0b00100,
            0b00000
            )
        backspace_char = (
            0b00000,
            0b00000,
            0b00111,
            0b01001,
            0b10001,
            0b01001,
            0b00111,
            0b00000
                )
        enter_char = (
            0b00000,
            0b00001,
            0b00101,
            0b01001,
            0b11111,
            0b01000,
            0b00100,
            0b00000
            )

        lcd.create_char(0, wifi_char)
        lcd.create_char(1, backspace_char)
        lcd.create_char(2, enter_char)
        return lcd

    def _init_soundcard(self):
        mute_gpio = self._rsc.mute_gpio
        print("MamemasRadio, mute_gpio = ", mute_gpio)
        if(mute_gpio != 0):
            GPIO.setmode(GPIO.BCM)
            GPIO.setup(mute_gpio, GPIO.OUT, initial=GPIO.LOW)

    def start(self):
        """ This starts all the state model of the radio
        """
        self._state = self._off_state
        self._state.enter_state()
        self._wifi_thread.start()
        stopped = False
        while not stopped:
            try:
                event = self._event_queue.get()
                self.logger.info("Got event %s", event)
                self._state.handle_event(event)
                self._event_queue.task_done()
            except BaseException:
                self.logger.error("Stopped")
                self.logger.error(traceback.format_exc())
                self._wifi_thread.stop()
                self._ctxt.lcd.backlight_enabled = False
                self._ctxt.lcd.clear()
                self._ctxt.power_button.clear()
                self._ctxt.station_button.clear()
                self._ctxt.volume_button.clear()
                GPIO.setup(self._rsc.mute_gpio, GPIO.OUT, initial=GPIO.HIGH)
                GPIO.setup(self._rsc.mute_gpio, GPIO.IN)
                GPIO.cleanup()
                self._on_state.cleanup()
                self._off_state.cleanup()
                stopped = True


if __name__ == "__main__":

    arg_parser = argparse.ArgumentParser()
    arg_parser.add_argument("-c", "--config",
                            help="pathname of configuration file",
                            default="webradio.cfg")
    arg_parser.add_argument("-ll", "--log_level",
                            help="define logging level",
                            choices=["debug", "info", "warning", "error"],
                            default="info")
    arg_parser.add_argument("-lf", "--logfile",
                            help="define the logfile, console if none")
    # TODO : check how to use the logfile argument
    args = arg_parser.parse_args()

    levels = {"debug": logging.DEBUG,
              "info": logging.INFO,
              "warning": logging.WARNING,
              "error": logging.ERROR}
    logging.basicConfig(format='%(levelname)s:%(asctime)s:%(message)s',
                        level=levels[args.log_level]
                        #filename=args.logfile
                        )
    logger = logging.getLogger(__name__)

    logging.info("Arguments : %s", args)

    radio = MamemasRadio(args.config)
    radio.start()

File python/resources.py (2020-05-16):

#!/usr/bin/env python3
# -*- coding: utf-8 -*-
"""
Created on Sat Sep 15 12:34:19 2018

@author: Sebastien Roy
"""

import configparser
import datetime
import logging


class Resources:
    """ This class is used to get all the values from configuration files
    """
    GENERAL_SECTION = "general"
    WELCOME_ENTRY = "welcome_msg"
    DEFAULT_WELCOME_MSG = "Bonjour Maman!"
    SCROLL_RATE_ENTRY = "scroll_rate"
    SCROLL_BEGIN_ENTRY = "scroll_begin_delay"
    SCROLL_END_ENTRY = "scroll_end_delay"
    CHOOSE_TIMEOUT_ENTRY = "choose_timout"
    VOLUME_TIMEOUT_ENTRY = "volume_timout"
    BT_DISCOVERABLE_TIMEOUT_ENTRY = "bt_discoverable_timeout"
    VOLUME_INCREMENT_ENTRY = "volume_increment"

    WIFI_SECTION = "wifi"
    WIFI_FILENAME_ENTRY = "filename"
    WIFI_TEMPLATE_ENTRY = "template"
    POST_VALIDATE_ENTRY = "post_validate"

    I18N_SECTION = "i18n"
    NO_TITLE_ENTRY = "no_title_msg"
    BT_PLAYBACK_ENTRY = "bt_playback_msg"
    CHANGE_STATION_ENTRY = "change_station"
    CONFIRM_CHANGE_ENTRY = "confirm_change"
    NETWORK_CHOICE_ENTRY = "network_choice"
    PLEASE_TURN_ENTRY = "please_turn"
    PLEASE_PRESS_ENTRY = "please_press"
    ENTER_PWD_ENTRY = "enter_pwd"
    PRESS_ENTER_ENTRY = "press_enter"
    REBOOT_ENTRY = "reboot"
    VOLUME_MSG_ENTRY = "volume"

    RANDOM_MSG_SECTION = "random_messages"
    DATED_MSG_SECTION = "dated_messages"
    PLAYLIST_SECTION = "playlist"

    WELCOME_MSG_MAX_SIZE = 16
    MSG_MAX_SIZE = 20

    HARDWARE_SECTION = "hardware"
    LCD_ADDRESS_ENTRY = "lcd_address"
    POWER_SWITCH_ENTRY = "power_switch"
    POWER_LED_ENTRY = "power_led"
    STATION_BUTTON_ENTRY = "station_button"
    VOLUME_BUTTON_ENTRY = "volume_button"
    MUTE_ENTRY = "mute"

    SLEEP_SECTION = "sleep"

    CLOCK_SECTION = "clock"
    CLOCK_FORMAT_ENTRY = "format"

    def __init__(self, config_file_path):
        self.logger = logging.getLogger(type(self).__name__)
        self._configParser = configparser.RawConfigParser()
        self._config_file_path = config_file_path
        self._welcome_msg = ""
        try:
            self._configParser.read(config_file_path, encoding='utf-8')
            self._welcome_msg = self._configParser.get(Resources.GENERAL_SECTION,
                                                       Resources.WELCOME_ENTRY)

            entries = self._configParser.items(Resources.RANDOM_MSG_SECTION)
            self._msgs = [y for x, y in entries]
            sleep_entries = self._configParser.items(Resources.SLEEP_SECTION)
            self._sleep_lines = [y.strip("\"") for x, y in sleep_entries]
            if len(self._sleep_lines) > 4:
                self._sleep_lines = self._sleep_lines[:4]

        except configparser.NoSectionError as nosection:
            self.logger.error("Error: %s in configuration file: %s",
                              nosection,
                              self._config_file_path)
        except configparser.NoOptionError as nosection:
            self.logger.error("Error: %s in configuration file: %s",
                              nosection,
                              self._config_file_path)
        return

    def get_i18n(self, entry):
        return self._configParser.get(Resources.I18N_SECTION, entry)

    def _get_lcd_address(self):
        address = ""
        try:
            address = self._configParser.get(Resources.HARDWARE_SECTION,
                                             Resources.LCD_ADDRESS_ENTRY)
        except:
            address = "0x27"
        return int(address, 0)  # let it guess the base from the format

    def _get_welcome_msg(self):
        msg = self._welcome_msg if self._welcome_msg \
                        else Resources.DEFAULT_WELCOME_MSG
        return msg if len(msg) <= Resources.WELCOME_MSG_MAX_SIZE \
                        else msg[0: Resources.WELCOME_MSG_MAX_SIZE]

    def _get_today_msg(self):
        today_msg = ""
        today = datetime.date.today()
        dated_msgs = self._configParser.items(Resources.DATED_MSG_SECTION)
        for key, msg in dated_msgs:
            day_month = key.split("/")
            day = int(day_month[0])
            month = int(day_month[1])
            if day == today.day and month == today.month:
                today_msg = msg
                break
        return today_msg;

    def _get_msgs(self):
        return self._msgs

    def _get_power_switch(self):
        str = self._configParser.get(Resources.HARDWARE_SECTION, Resources.POWER_SWITCH_ENTRY)
        return int(str, 0)

    def _get_power_led(self):
        str = self._configParser.get(Resources.HARDWARE_SECTION, Resources.POWER_LED_ENTRY)
        return int(str, 0)

    def _get_sleep_lines(self):
        return self._sleep_lines

    def _get_clock_format(self):
        return self._configParser.get(Resources.CLOCK_SECTION,
                                      Resources.CLOCK_FORMAT_ENTRY)

    def _get_wifi_filename(self):
        return self._configParser.get(Resources.WIFI_SECTION,
                                      Resources.WIFI_FILENAME_ENTRY)

    def _get_wifi_template(self):
        return self._configParser.get(Resources.WIFI_SECTION,
                                      Resources.WIFI_TEMPLATE_ENTRY)

    def _get_wifi_post_validate(self):
        return self._configParser.get(Resources.WIFI_SECTION,
                                      Resources.POST_VALIDATE_ENTRY)

    def _get_scroll_rate(self):
        return float(self._configParser.get(Resources.GENERAL_SECTION,
                                            Resources.SCROLL_RATE_ENTRY))

    def _get_scroll_begin(self):
        return float(self._configParser.get(Resources.GENERAL_SECTION,
                                            Resources.SCROLL_BEGIN_ENTRY))

    def _get_scroll_end(self):
        return float(self._configParser.get(Resources.GENERAL_SECTION,
                                            Resources.SCROLL_END_ENTRY))

    def _get_choose_timeout(self):
        return float(self._configParser.get(Resources.GENERAL_SECTION,
                                            Resources.CHOOSE_TIMEOUT_ENTRY))

    def _get_volume_timeout(self):
        return float(self._configParser.get(Resources.GENERAL_SECTION,
                                            Resources.VOLUME_TIMEOUT_ENTRY))

    def _get_bt_discoverable_timeout(self):
        return float(self._configParser.get(Resources.GENERAL_SECTION,
                                            Resources.BT_DISCOVERABLE_TIMEOUT_ENTRY))

    def _get_volume_increment(self):
        return float(self._configParser.get(Resources.GENERAL_SECTION,
                                            Resources.VOLUME_INCREMENT_ENTRY))

    def _get_playlist(self):
        return self._configParser.items(Resources.PLAYLIST_SECTION)

    def _get_station_button(self):
        str = self._configParser.get(Resources.HARDWARE_SECTION, Resources.STATION_BUTTON_ENTRY)
        return [int(val.strip()) for val in str.split(",")]
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

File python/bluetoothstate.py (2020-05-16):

#!/usr/bin/python3
# -*- coding: utf-8 -*-
"""
Created on Sun May 10 19:38:01 2020

@author: Sébastien ROY
"""
import logging
import subprocess
import random
import datetime
import time
from threading import Thread, Event

import RPi.GPIO as GPIO

from radiostate import RadioState
from volumestate import VolumeState
from btidlestate import BtIdleState
from resources import Resources
from scrollingtext import ScrollingText
from radioevents import TextUpdateEvent, TextFieldType, PowerButtonEvent, StationButtonEvent, VolumeButtonEvent, VolumeTimeoutEvent
from powerbutton import PowerEvent
from encoder import EncoderEvent

class BlinkingThread(Thread):
    """ A thread used to blink the display background when bluetooth is discoverable
    """
    def __init__(self, callback):
        Thread.__init__(self)
        self._callback = callback
        self._stop = False
        self._pause = Event()

    def stop(self):
        """ Stops the thread
        """
        self._stop = True

    def pause(self):
        """ Pauses the thread
        """
        self._pause.clear()

    def resume(self):
        """ Resumes the thread
        """
        self._pause.set()

    def run(self):
        while not self._stop:
            self._pause.wait()
            time.sleep(0.5)
            self._callback()


class BluetoothState(RadioState):
    """ Bluetooth state is entered when the radio is off and the user press the
    station button. The bluetooth state allows to play from a phone (for instance)
    to the radio through bluetooth.
    There is two substates :
        - BtPlayback, that is the entry substate of the bluetooth state. The is
        Nothing more
        - BtDiscoverable, that allows bt client devices to discover the radio.
    """

    def __init__(self, context, owner):
        RadioState.__init__(self, context, owner)
        self.logger = logging.getLogger(type(self).__name__)

        # Random msg inittialisation
        self.random_msg = ""
        self._random_msg_display = ScrollingText(self._random_msg, self._random_msg_callback,
                                           display_size=20, refresh_rate=0,
                                           scroll_begin_delay=self._ctxt.rsc.scroll_begin,
                                           scroll_end_delay=self._ctxt.rsc.scroll_end,
                                           scroll_rate=self._ctxt.rsc.scroll_rate)
        self._random_msg_display.start()
        self._random_msg_display.pause()

        # clock initialisation
        self._clock_rolling_text = ScrollingText(self._get_time_text,
                                                 self._time_callback,
                                                 display_size=5,
                                                 refresh_rate=1)
        self._clock_rolling_text.start()
        self._clock_rolling_text.pause()

        self._blink_thread = None
        self._blinking = False
        # substates
        self._volume_state = VolumeState(self._ctxt, self)
        self._idle_state = BtIdleState(self._ctxt, self)
        self._sub_state = None
        
        # ensure the bluetooth device is pairable
        subprocess.call(["bluetoothctl", "pairable", "on"])
        subprocess.call(["bluetoothctl", "agent", "NoInputNoOutput"]) 
        subprocess.call(["bluetoothctl", "default-agent"]) 

        return

    def enter_state(self):
        """ Assumption : the Audio Profile Sink Role has been enabled
            switch on soundcard
            echo "power on" | bluetoothctl
            echo "pairable on" | bluetoothctl
            bluealsa-aplay 00:00:00:00:00:00
        """
        self.logger.debug("Entering BluetoothState ")

        self.random_msg = self._ctxt.rsc.today_msg
        if not self.random_msg:
            self.random_msg = random.choice(self._ctxt.rsc.random_msgs)

         # switch on the soundcard
        mute_gpio = self._ctxt.rsc.mute_gpio
        if mute_gpio != 0:
            GPIO.output(mute_gpio, GPIO.HIGH)
        # power on the bluetooth stuff
        subprocess.call(["bluetoothctl", "power", "on"])
        # play what users want to
        self._aplay_proc = subprocess.Popen(["bluealsa-aplay","00:00:00:00:00:00"])

        self._ctxt.lcd.clear()
        self._ctxt.lcd.backlight_enabled = True
        self._ctxt.power_button.led = True

        self._display_welcome()

        self._sub_state = self._idle_state
        self._sub_state.enter_state()

        self._clock_rolling_text.resume()
        self._random_msg_display.resume()
        return

    def leave_state(self):
        #close all the bluetooth stuff
        self._aplay_proc.kill()
        #subprocess.call(["bluetoothctl" ,"pairable", "off"])
        subprocess.call(["bluetoothctl", "power", "off"])

        self._stop_blinking()
        self._clock_rolling_text.pause()
        self._random_msg_display.pause()
        return

    def handle_event(self, event):
        if type(event) is PowerButtonEvent and event.value == PowerEvent.SWITCH_PRESSED:
            self._owner.switch_radio(True)
        elif type(event) is StationButtonEvent and event.value == EncoderEvent.SWITCH_PRESSED:
            # TODO : switch to discoverabe during a few seconds
            if self._blinking :
                self._stop_blinking()
            else:
                self._start_blinking()
        elif type(event) is VolumeTimeoutEvent:
            self._leave_volume()
        elif type(event) is VolumeButtonEvent:
            self._change_volume(event)
        elif type(event) is TextUpdateEvent and event.originator == TextFieldType.RANDOM_MSG:
            self._ctxt.lcd.cursor_pos = (1, 0)
            self._ctxt.lcd.write_string(event.value.ljust(20))
        elif type(event) is TextUpdateEvent and event.originator == TextFieldType.BT_CLOCK:
            self.logger.debug("writing clock string : %s", event.value)
            self._ctxt.lcd.cursor_pos = (0, 15)
            self._ctxt.lcd.write_string(event.value.rjust(5))
        return

    def cleanup(self):
        return

    def _leave_volume(self):
        if self._sub_state == self._volume_state:
            self._sub_state.leave_state()
            self._sub_state = self._idle_state
            self._sub_state.enter_state()

    def _change_volume(self, event):
        if self._sub_state == self._volume_state:
            self._sub_state.handle_event(event)
        else:
            self._volume_state.increment(event.value)
            self._sub_state.leave_state()
            self._sub_state = self._volume_state
            self._sub_state.enter_state()

    def _display_welcome(self):
         msg = self._ctxt.rsc.welcome_msg.ljust(Resources.WELCOME_MSG_MAX_SIZE)
         self._ctxt.lcd.cursor_pos = (0, 0)
         self._ctxt.lcd.write_string(msg)
         return

    def _get_time_text(self):
        dtg = datetime.datetime.today()
        return dtg.strftime(self._ctxt.rsc.clock_format)
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

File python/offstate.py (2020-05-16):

#!/usr/bin/env python3
# -*- coding: utf-8 -*-
"""
Created on Sat Apr 18 17:28:02 2020

@author: Sebastien Roy
"""
#import random
import subprocess
import os.path
import os
import re
from shutil import copyfile
import logging

import RPi.GPIO as GPIO

from radiostate import RadioState
from essidstate import EssidState, PasswdState
from sleepstate import SleepState
from resources import Resources

class OffState(RadioState):
    """ This class defines the behaviour of the off state
    """
    def __init__(self, context, owner):
        RadioState.__init__(self, context, owner)
        self.logger = logging.getLogger(type(self).__name__)
        self._essid_state = EssidState(context, self)
        self._passwd_state = PasswdState(context, self)
        self._sleep_state = SleepState(context, self)
        self._sub_state = None

    def handle_event(self, event):
        self._sub_state.handle_event(event)

    def enter_state(self):
        self.logger.debug("Entering state")
        self._ctxt.power_button.led = False
        proc = subprocess.Popen(["mpc", "stop"], stdout=subprocess.PIPE, universal_newlines=True)
        out, err = proc.communicate()
        # switch off the soundcard
        mute_gpio = self._ctxt.rsc.mute_gpio
        if mute_gpio != 0:
            GPIO.output(mute_gpio, GPIO.LOW)

        self._sub_state = self._sleep_state
        self._sub_state.enter_state()

    def switch_radio(self, state):
        self._owner.switch_radio(state)

    def enter_choose_essid(self):
        self._sub_state.leave_state()
        self._sub_state = self._essid_state
        self._sub_state.enter_state()

    def enter_choose_pwd(self):
        self._sub_state.leave_state()
        self._sub_state = self._passwd_state
        self._sub_state.enter_state()

    def leave_state(self):
        self.logger.debug("Leaving state")
        self._sub_state.leave_state()

    def wifi_configured(self):
        essid = self._essid_state.essid
        password = self._passwd_state.password
        template = self._ctxt.rsc.wifi_template
        wpa_content = template.format(essid, password)
        wpa_filename = self._ctxt.rsc.wifi_filename
        try:
            backup_file(wpa_filename)
            f = open(wpa_filename, "w")
            f.write(wpa_content)
            f.close()
        except:
            print("Error while trying to save wpa file :", wpa_filename)
        lcd = self._ctxt.lcd
        lcd.clear()
        lcd.backlight_enabled = True
        lcd.cursor_pos = (0, 0)
        reboot = self._ctxt.rsc.get_i18n(Resources.REBOOT_ENTRY).ljust(20)
        lcd.write_string(reboot)
        # The reboot shall be written in the config file
        reboot_cmd = self._ctxt.rsc.wifi_post_validate
        subprocess.call(reboot_cmd.split(" "))

    def cleanup(self):
        self.logger.debug("deleting off state")
        self._essid_state.cleanup()
        self._passwd_state.cleanup()
        self._sleep_state.cleanup()
        
    def switch_to_bluetooth(self):
        self._owner.switch_to_bluetooth()

def backup_file(filename, last=99):
    logger = logging.getLogger(__name__)
    if not os.path.exists(filename):
        return
    logger.info("Backing up file : %s", filename)
    nb_size = len(str(last))
    # searching if already a backup file
    m = re.search("_back\d+$", filename)
    backup_filename = ""
    nb = 0
    if m is None:
        backup_filename = filename + "_back" + str(1).zfill(nb_size)
    else:
        prefix = filename[:len(filename)-len(m.group(0))]
        nb_m = re.search("\d*$", m.group(0))
        nb = int(nb_m.group(0)) + 1
        backup_filename = prefix + "_back" + str(nb).zfill(nb_size)

    if nb < last:
        backup_file(backup_filename, last)

    copyfile(filename, backup_filename)
    logger.debug("End of backup of : %s", filename)
    return

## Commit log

2019-09-01 add pcb design files
    [Accessoires.fzz, accessories_pcb.fzz, sketch_for_parts.fzz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]
2019-09-01 remove drafts
    [Accessoires.fzz, sketch_for_parts.fzz, webradio_sketch-2.fzz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]
2020-04-10 add git ignore and config file
    [webradio.cfg]
2020-04-10 closes #2
    [webradio.cfg]
2020-04-13 Update readme.txt
    Add link to PCB manufacturing pages
2020-04-14 Fix commandline argument handling
    [mamemasradio.py]
2020-04-18 display clock in sleep mode
    [webradio.cfg]
2020-04-18 Add clock display when the title is not available
    [webradio.cfg]
2020-04-19 Some work on the manuals
    [webradio.cfg]
2020-05-16 Ca fonctionne, il reste le volume à gerer
    [webradio.cfg]
2020-05-16 bluetooth is now implemented
    [webradio.cfg]
